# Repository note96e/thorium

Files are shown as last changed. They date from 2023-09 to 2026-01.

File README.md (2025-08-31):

# Thorium keyboard
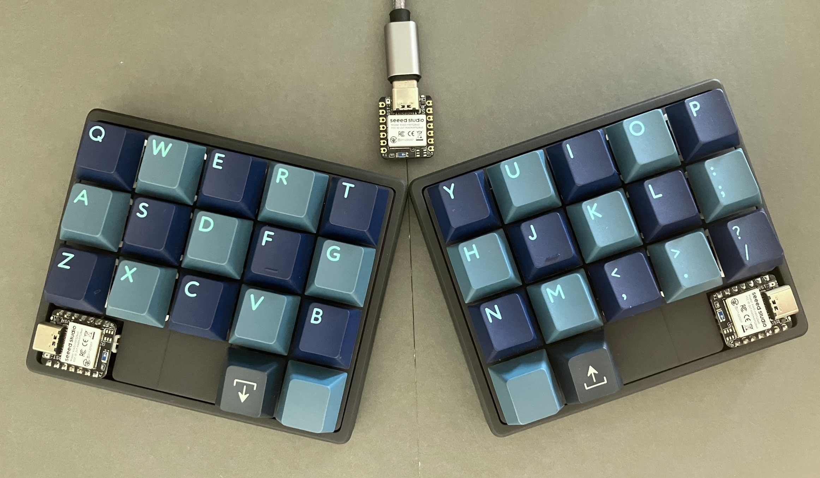
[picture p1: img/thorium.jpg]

> [!NOTE]
> The design of the case and plate has been partially updated. Please be aware that the actual product may differ slightly from the photos shown.
## Features
- ortholinear  
- 34-keys
- wireless
- split
- dongle  
- MX switches, hotswap 
- small PCB (96mm*77mm)
- 3D printed cases and plates
- lipo battery (260mAh)
- Seeed Studio XIAO nRF52840
- ZMK Firmware
- ZMK Studio  
- (Optional) Raytac MDBT50Q-RX
- (Optional) foam (reduce noise) 
## Resources
- [Build guide](./doc/buildguide.md)
- PCB files (KiCad7, .zip(gerbers)): [Left](https://github.com/note96e/thorium/tree/main/pcbl) | [Right](https://github.com/note96e/thorium/tree/main/pcbr)
- [3DP files (.f3d, .step)](https://github.com/note96e/thorium/tree/main/case)
- [Foam design files (.svg)](https://github.com/note96e/thorium/tree/main/foam)
- ZMK Firmware configuration files: [Config](https://github.com/note96e/thorium-zmk-config) | [Reset](https://github.com/note96e/thorium-reset-zmk-config)

## License
- [MIT](https://github.com/note96e/thorium/blob/main/LICENSE.txt)

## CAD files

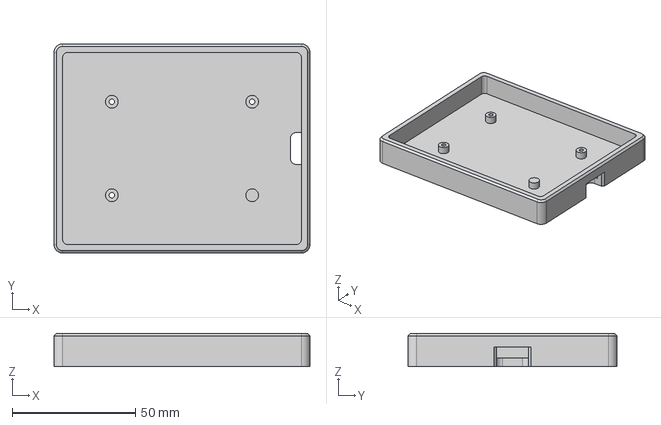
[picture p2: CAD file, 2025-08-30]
case/thorium_case_right.step
104.0 x 85.0 x 13.5 mm

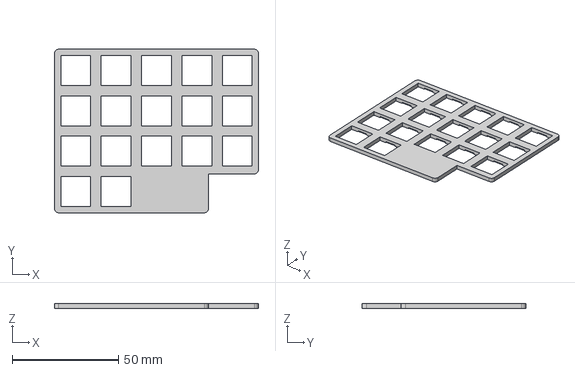
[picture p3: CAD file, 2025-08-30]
case/thorium_plate_right.step
96.0 x 77.0 x 2.20 mm

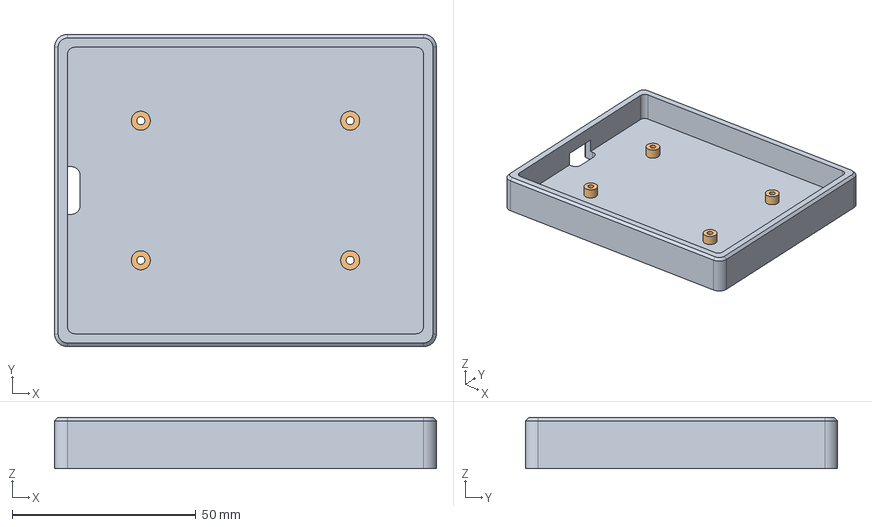
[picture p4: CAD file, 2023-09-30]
case/thorium_case.step
104.0 x 85.0 x 14.0 mm

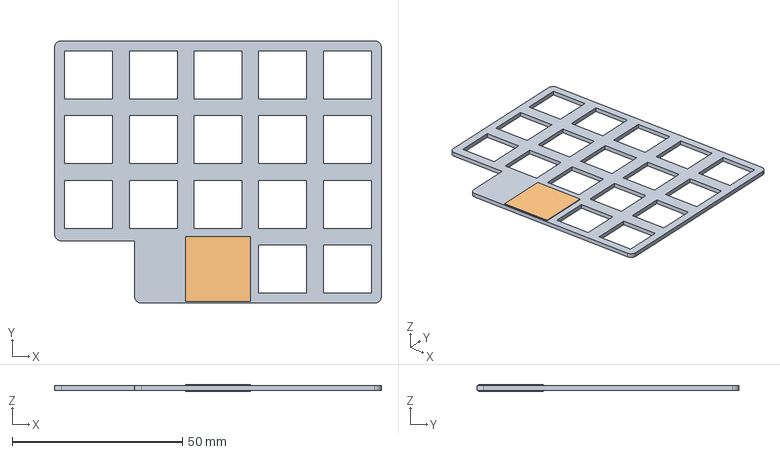
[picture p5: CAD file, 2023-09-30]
case/thorium_plate.step
96.0 x 77.0 x 2.00 mm

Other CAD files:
case/thorium_case_left.step
case/thorium_plate_left.step
case/old/thorium.f3d
case/thorium.f3d
case/thorium4.f3d

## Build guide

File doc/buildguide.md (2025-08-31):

# Build guide

## Parts list

### 3D printed parts
> [!NOTE]
> The design of the case and plate has been partially updated. Please be aware that the actual product may differ slightly from the photos shown.

- Case (Left:1 Right:1)
- Switch Plate (Left:1 Right:1)

You can download Fusion 360 files (.f3d) and STEP files. Files with the old design are stored in the `old` folder.    
https://github.com/note96e/thorium/tree/main/case  
STEP files can be used to order PCBs from JLCPCB (Black Resin is recommended).  

### PCB (Thickness: 1.6mm)
You can download KiCAD7 data.  
- Left half (1)
    - https://github.com/note96e/thorium/tree/main/pcbl
- Right half (1)
    - https://github.com/note96e/thorium/tree/main/pcbr

These files are Gerber files that can be used to order PCBs from JLCPCB.
`thorium_pcbl.zip`, `thorium_pcbr.zip`

### Parts to be soldered to the front side of PCB
- Pogo pin: RTLECS GB15-07020-0818-2A (4)
    - AliExpress https://www.google.com/search?q=RTLECS+GB15-07020-0818-2A
- JST PH box header: S2B-PH-K-S (2)
- 7x1 female socket header THD pitch: 2.54mm height 3.5mm (4)

### Parts to be soldered to the back side of PCB
- Diode: 1N4148 / 1N4148W SOD-123 (34)
- Kailh hot swapping pcb socket for MX switch (34)
- Power switch: MSK-12D19 (2)
    - AliExpress https://www.google.com/search?q=MSK-12D19

### Other parts
- Seeed Studio XIAO nRF52840 (3)
- 7x1 male pin header THD pitch: 2.54mm height 2.5mm (4)
- Lipo Battery: EEMB LP601730 with JST PH Connector 3.7V 260mAh (2)
    - Amazon  https://www.amazon.com/dp/B09DPN31KM
- Cherry MX switch or compatible (34)
- Keycaps for Cherry MX switch (34)
- Countersunk Head Screw M2 10mm (6)
- Hex nut M2 1.2mm (6)
- Bumpon
- Type-C USB Cable

> [!NOTE]
> Pogo pins and Lipo batteries are not widely available. Alternatives may not work well.
  
> [!CAUTION]
> When using Lipo batteries, make sure they have an over-discharge protection circuit and that the polarity is correct.

## Tools
- Soldering iron
- Solder
- Solder wick
- Flux (Recommended)
- Flux remover (Recommended)
- Tweezers
- Screwdriver

# Assembly
Assemble each half of the keyboard in the following order.
- Solder the parts on the back side of the PCB.  
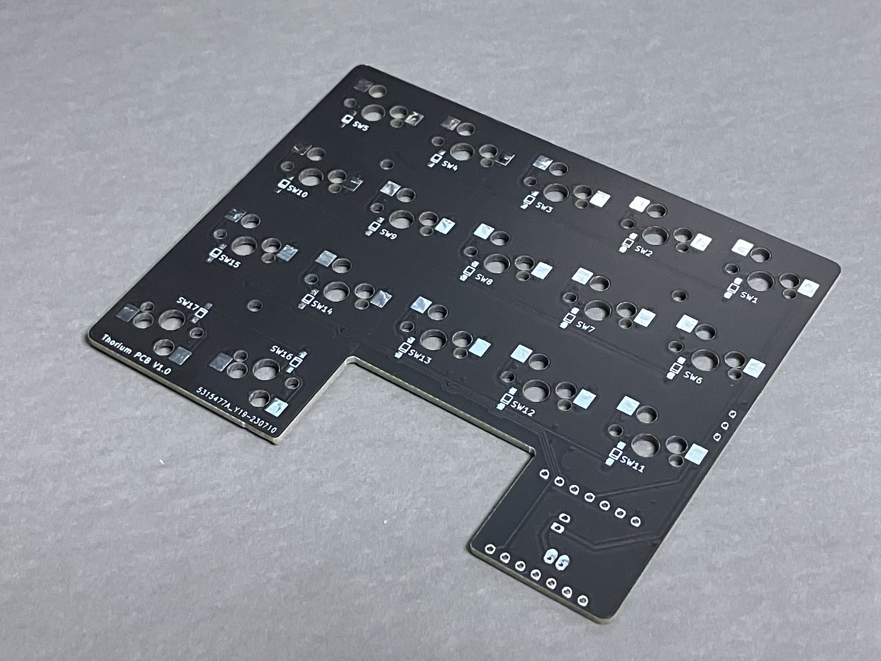
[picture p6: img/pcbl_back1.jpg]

    - Diodes (Red. Note orientation) -> Switch sockets (Blue) -> Power switch (Green)
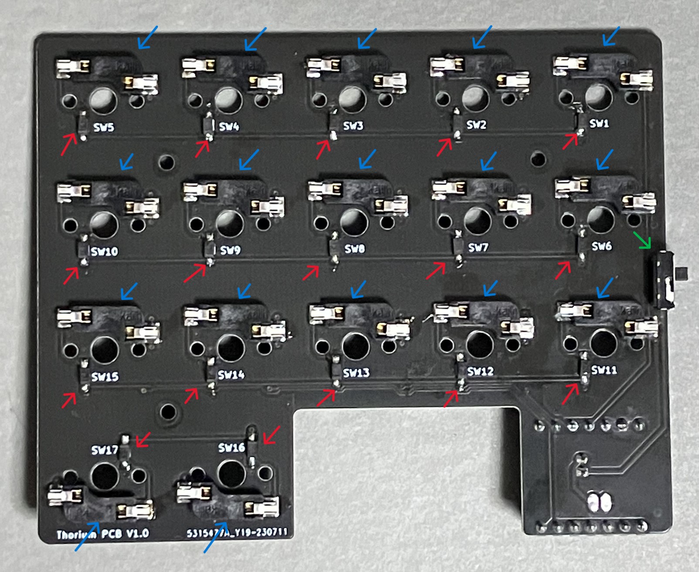
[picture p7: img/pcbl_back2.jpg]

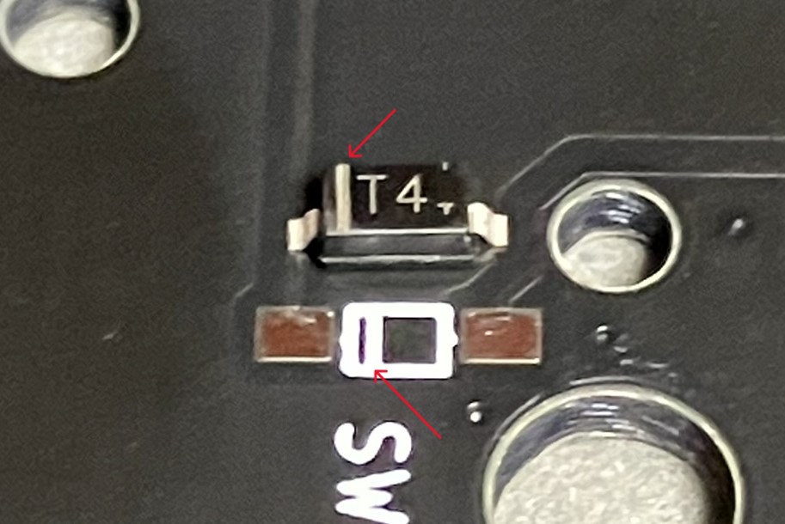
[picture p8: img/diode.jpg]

- Solder the parts on the front side of the PCB.
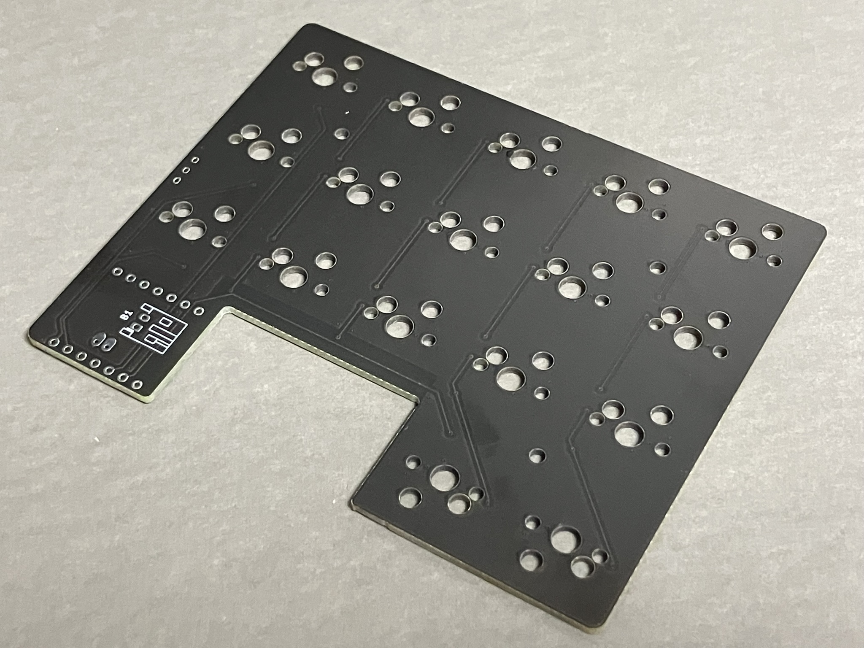
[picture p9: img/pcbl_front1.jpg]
  
    - Pogo pins (Red) -> JST PH box header (Blue) -> Socket headers (Green)
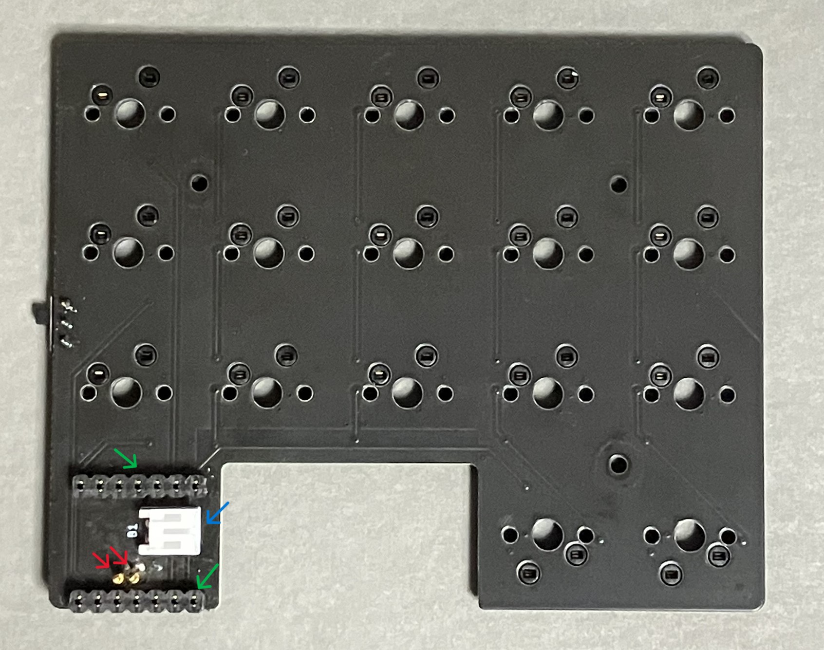
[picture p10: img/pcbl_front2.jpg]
  
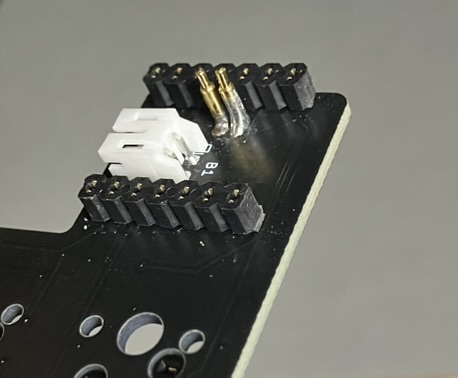
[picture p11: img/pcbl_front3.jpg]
  
- Solder male pin headders to XIAO.
- Install the battery.
- Install XIAO.
- Fix the PCB to the case with screws and nuts.  
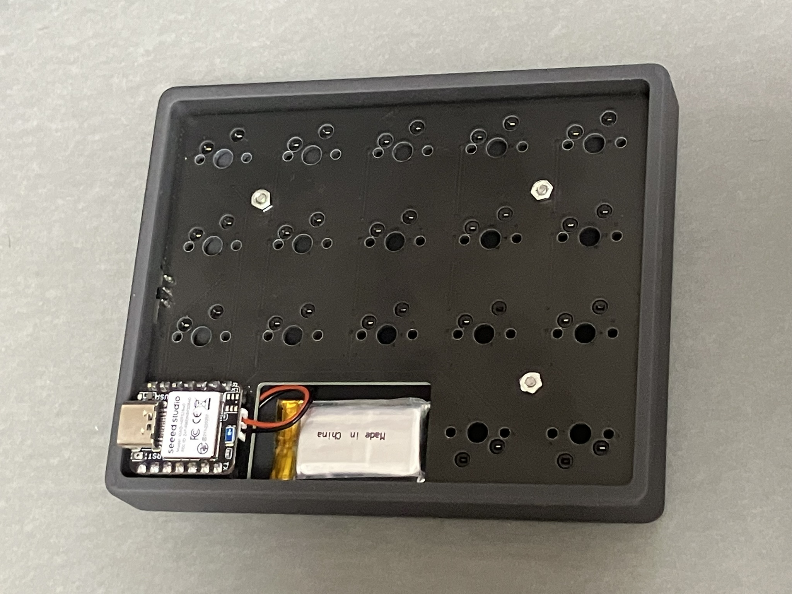
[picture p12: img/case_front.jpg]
  
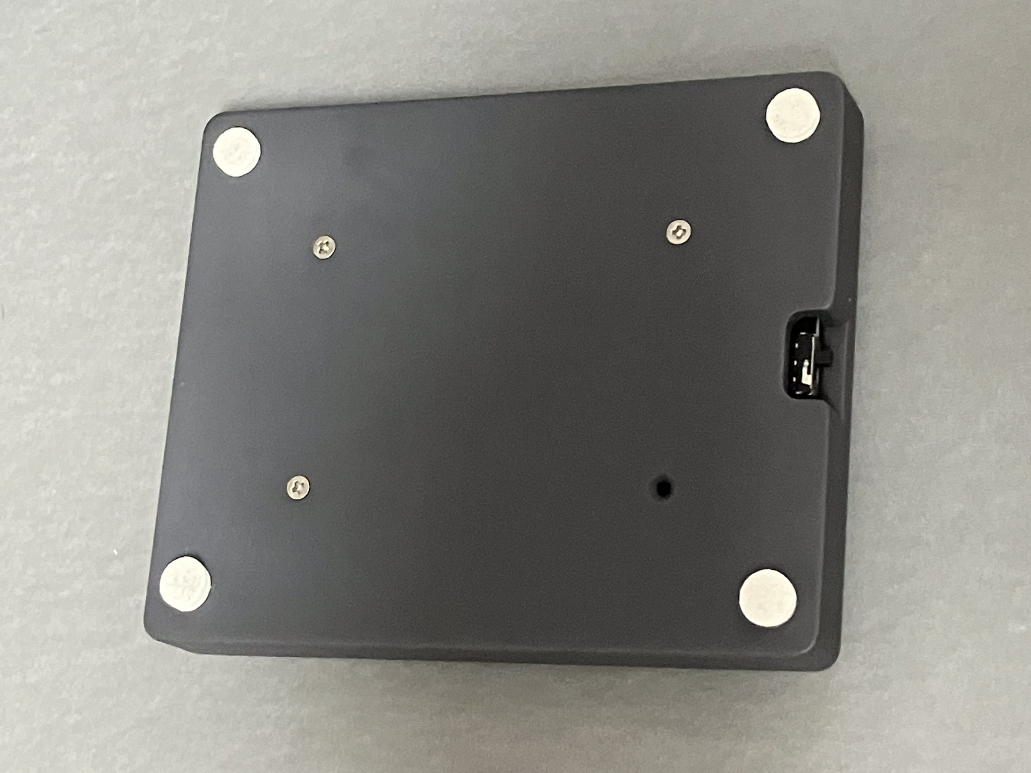
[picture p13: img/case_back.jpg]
 
- Install the MX switches.
    - Install the switches on the four corners into the switch plate, then install them on the PCB.
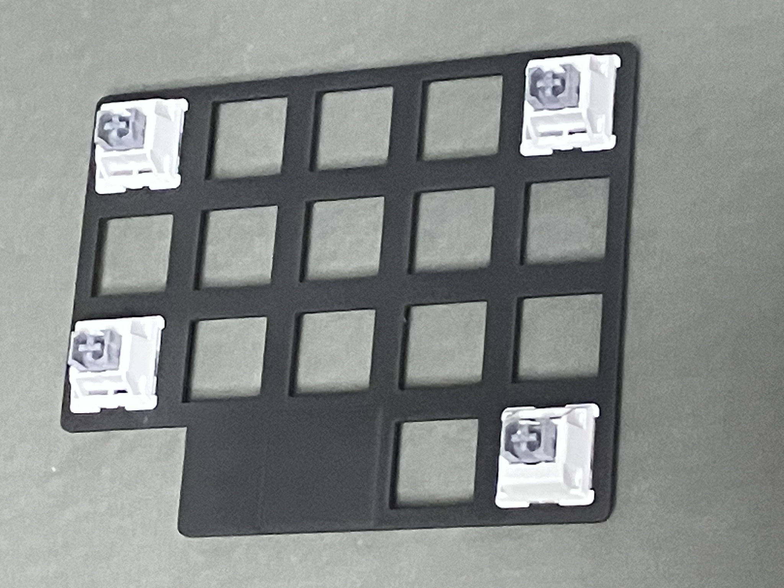
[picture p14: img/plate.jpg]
 
    - Install the remaining switches.
- Install the keycaps.

> [!NOTE]
>Pogo pins must be soldered vertically to avoid shorts and contact failures. I could not find a way to solder them well. 

> [!NOTE]
>The distance between the back side of XIAO and the front side of the PCB is 6 to 7 mm. Cut the pins of the pin headers to adjust if necessary.

## Charging
Charge the battery after assembly.  
Connect XIAO to a PC or charger with the USB cable, and turn the slide switch ON (front side). The green LED on XIAO will light up and charging will begin.  
When charging is complete, the green LED will turn off. Disconnect the USB cable and turn the slide switch OFF.

# Firmware
Please refer to the official ZMK Firmware documentation for instructions on how to flash firmware, change keymap, etc.   
The latest firmware supports ZMK Studio.

You can download UF2 file from the following link.  
https://github.com/note96e/thorium-zmk-config/releases  
After downloading, unzip the thorium-x.x.x.zip file.
- Dongle: `thorium_dongle-seeeduino_xiao_ble-zmk.uf2`  
- Left half: `thorium_left-seeeduino_xiao_ble-zmk.uf2`  
- Right half: `thorium_right-seeeduino_xiao_ble-zmk.uf2`  

You can download the UF2 file for the dongle and each half pairing reset.   
https://github.com/note96e/thorium-reset-zmk-config/releases  
After downloading, unzip the thorium-reset-x.x.x.zip file. 
- Dongle: `thorium_reset_dongle-seeeduino_xiao_ble-zmk.uf2`  
- Left half: `thorium_reset_left-seeeduino_xiao_ble-zmk.uf2`  
- Right half: `thorium_reset_right-seeeduino_xiao_ble-zmk.uf2`  

In the left and right halves, the first row of keys is assigned to &bootloader.

## Default keymap
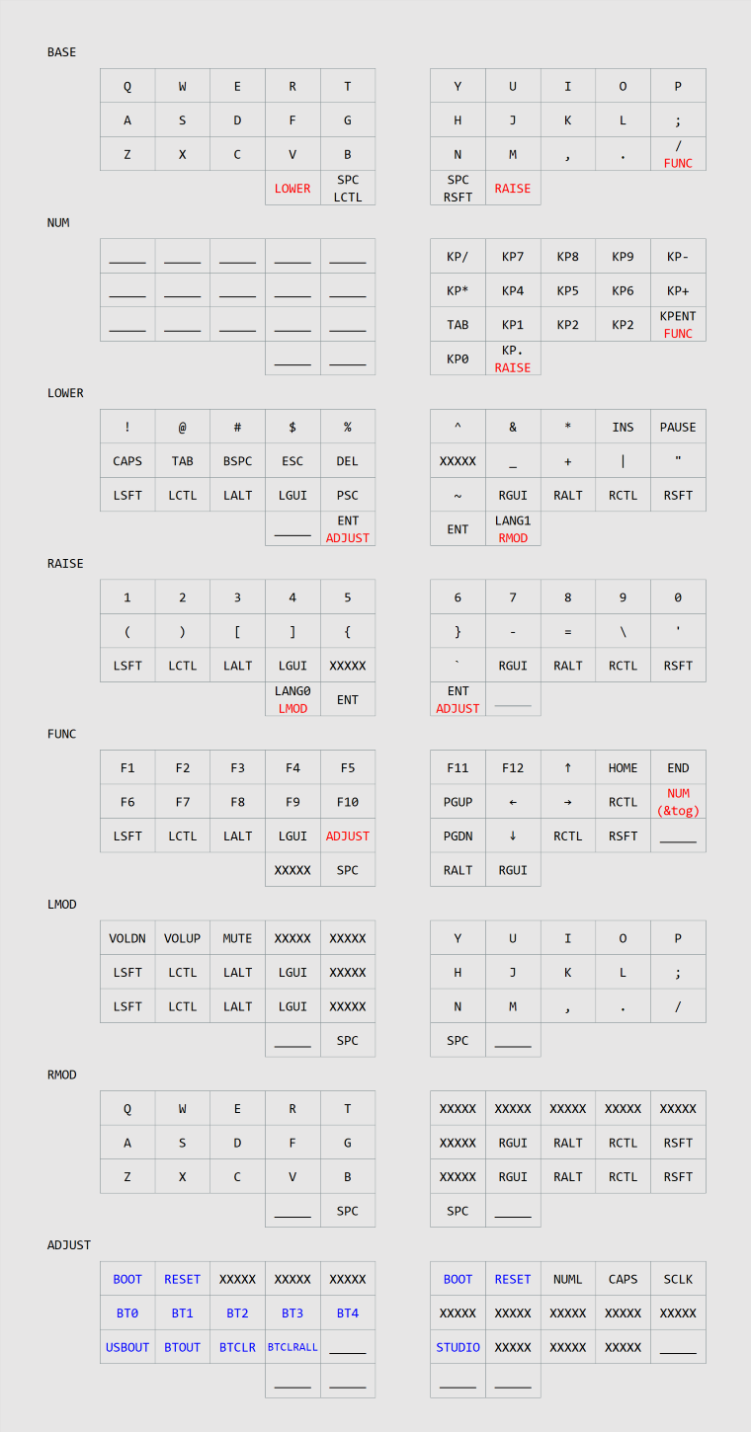
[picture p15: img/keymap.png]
  
The second line describes the behavior when holding the key.  
The red text turns on the layer when the key is held.  
The blue text is assigned the following key codes in ZMK.  
- BOOT: &bootloader
- RESET: &sys reset
- BT0 ~ BT4: &bt BT_SEL 0 ~ &bt BT_SEL 4
- USBOUT: &out OUT_USB
- BTOUT: &out OUT_BLE
- BTCLR: &bt BT_CLR
- BTCLRALL: &bt BT_CLR_ALL
- STUDIO: &studio_unlock  

The following outlines how key codes relate to USB and Bluetooth connectivity.  
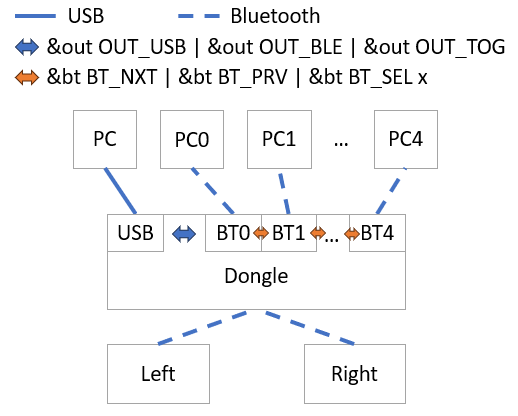
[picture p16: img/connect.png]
  

## Raytac MDBT50Q-RX
You can use the Raytac MDBT50Q-RX as a dongle in place of the XIAO, but it must have the UF2 bootloader installed.  
Use `thorium_dongle-raytac_mdbt50q_rx-zmk.uf2` and `thorium_reset_dongle-raytac_mdbt50q_rx-zmk.uf2`.

I'm currently using the module created by rschenk.
https://github.com/rschenk/zmk-component-raytac-dongle

## Building firmware locally
https://zmk.dev/docs/development/local-toolchain/setup  
After setting up the environment as described above, execute the steps below.
```
cd ~
git clone https://github.com/note96e/thorium-zmk-config.git
git clone https://github.com/note96e/thorium-reset-zmk-config.git
cd ~/zmk/app
# fw
west build -p -S studio-rpc-usb-uart -b seeeduino_xiao_ble -d build/thorium_dongle_xiao -- -DCONFIG_ZMK_STUDIO=y -DSHIELD=thorium_dongle -DZMK_CONFIG=/home/xxx/thorium-zmk-config
west build -p -b seeeduino_xiao_ble -d build/thorium_left -- -DSHIELD=thorium_left -DZMK_CONFIG=/home/xxx/thorium-zmk-config
west build -p -b seeeduino_xiao_ble -d build/thorium_right -- -DSHIELD=thorium_right -DZMK_CONFIG=/home/xxx/thorium-zmk-config
# reset
west build -p -b seeeduino_xiao_ble -d build/thorium_reset_dongle_xiao -- -DSHIELD=thorium_reset_dongle -DZMK_CONFIG=/home/xxx/thorium-reset-zmk-config
west build -p -b seeeduino_xiao_ble -d build/thorium_reset_left -- -DSHIELD=thorium_reset_left -DZMK_CONFIG=/home/xxx/thorium-reset-zmk-config
west build -p -b seeeduino_xiao_ble -d build/thorium_reset_right -- -DSHIELD=thorium_reset_right -DZMK_CONFIG=/home/xxx/thorium-reset-zmk-config
```
This will generate `~/zmk/app/build/thorium_*/zephyr/zmk.uf2`.  
### for Raytac MDBT50Q-RX
```
cd ~
git clone https://github.com/rschenk/zmk-component-raytac-dongle.git
cd ~/zmk/app
# fw
west build -p -S studio-rpc-usb-uart -b raytac_mdbt50q_rx -d build/thorium_dongle_raytac -- -DCONFIG_ZMK_STUDIO=y -DSHIELD=thorium_dongle -DZMK_CONFIG=/home/xxx/thorium-zmk-config -DZMK_EXTRA_MODULES=/home/xxx/zmk-component-raytac-dongle
# reset
west build -p -b raytac_mdbt50q_rx -d build/thorium_reset_dongle_raytac -- -DSHIELD=thorium_reset_dongle -DZMK_CONFIG=/home/xxx/thorium-reset-zmk-config -DZMK_EXTRA_MODULES=/home/xxx/zmk-component-raytac-dongle
```
# (Optional) Foam
Placing 3–3.5mm thick foam above and below the PCB helps reduce noise. The design files for the foam are stored below.
https://github.com/note96e/thorium/tree/main/foam  
By cutting the standoff sections of the keyboard case, the PCB can be supported by foam, resulting in a different typing feel.

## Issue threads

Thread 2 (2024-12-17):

[OT] Can you change the design as a custom request (paid)?

thecritic, 2024-12-17:
I love the idea behind the thorium, but I would love to have the bottom rows completely removed and then have the micro controllers sit underneath the pcb, so it would be a 3x5 each. Is that something that can be adjusted and hosted in a fork? I would pay for the adjustments.

note96e, 2024-12-17:
I believe it is possible to place the microcontroller on the underside of the pcb, but in a 3x5 layout there is no room for the battery.

thecritic, 2024-12-17:
you mean there is no place currently with the existing case right?

note96e, 2024-12-17:
There is a place for the current 4x5 size case; not so for the 3x3 size.
If you put the xiao on the underside of the pcb, you will need to (1) solder it directly to the pcb (like the TOTEM KB) and (2) add a reset switch.
The biggest problem is that the JST socket will be exposed; this will occur whether the JST socket is placed on the top or bottom side of the pcb.

thecritic, 2024-12-18:
If I were to design my own case, could you provide a PCB layout where the battery could be hidden underneath the pcb such that the connectors don't extend outside the case? There was one similar board called the "briq" which was similarly designed which I wanted to replicate, but without any detailed sources (also has a repo here on github). I just want a clean split wireless keyboard where basically the top is just made up of the 3x5 keys and everything else is hidden underneath the pcb
